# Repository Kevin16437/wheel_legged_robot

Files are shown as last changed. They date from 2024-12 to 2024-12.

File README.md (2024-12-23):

# 轮足机器人  
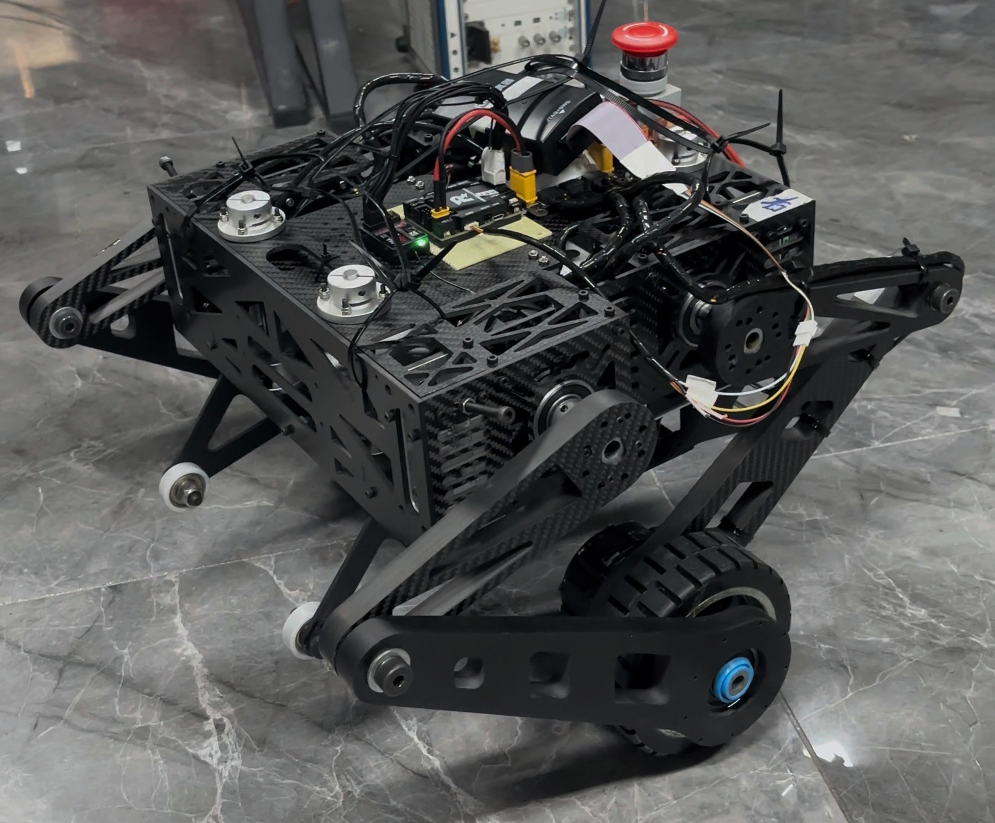
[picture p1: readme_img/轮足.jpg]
轮足

仍在更新完善。代码部分待继续补充说明。  
## 介绍  
本项目的轮足机器人包含6个电机，4个关节电机及2个轮毂电机均使用SG6010单编码器电机，预留出电池仓及主控螺丝孔位于机体底部。主控使用大疆robomaster C型开发板。  
主控代码部分包含另一个开源的仓库：[电机SDK](https://gitee.com/cyberbeast/mwmotorsdk).

## 目录
整个机器人项目被划分为多个部分，分别存放在仓库的不同目录中，每个部分都有更详细的说明，读者可根据需要进行查阅：  
 
- [`hardware`](hardware)：电源分线板PCB文件，由嘉立创专业版导出包含Gerber和AD文件。  
- [`matlab`](matlab)：算法仿真，包含模型建立、算法设计和仿真文件等。  
- [`software`](software)：主控程序，包含STM32代码工程。  
- [`solidworks`](solidworks)：机械结构设计，包含所有零件和总装配体模型文件。 
  
## 关于我们
北京守护兽科技有限公司是一家致力于电机驱动的技术公司，专注于伺服电机驱动板的研究与开发。本开源项目体现了我们对技术分享与社区建设的承诺，欢迎大家提出建议，共同完善和发展轮足机器人技术。
如需技术支持或合作，请联系： luoyongheng@cyberbeast.cn  

## 特别鸣谢  
感谢西格传动对本项目的大力支持。  
[西格传动官网](https://www.siggear.cn/)  

## 开源协议  
本项目采用 GNU 通用公共许可证 v3.0（GPL-3.0） 开源协议发布。你可以自由使用、修改和分发本项目的源代码，但请遵守以下条款：  

- 如果你修改了本项目的代码并发布，必须在发布的代码中包含原作者信息。  
- 发布的衍生作品必须在相同的GPL-3.0协议下发布。  
- 你在使用本项目时，如果与其他代码一起分发，必须将所有源代码公开。  
详细协议内容请参考[LICENSE](LICENSE)。  

***DRIVE THE WORLD WITH CYBERBEAST***

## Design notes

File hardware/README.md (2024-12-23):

# 电源分线板  
本电源分线板由XT60输入电池24V，给六个电机和主控板提供电源。XT30PW包含CAN线接口，每路XT30PW CAN接口可自行并联120Ω电阻（位于PCB背面），外引两路CAN线接口(一路用于调试，一路用于接主控板)。
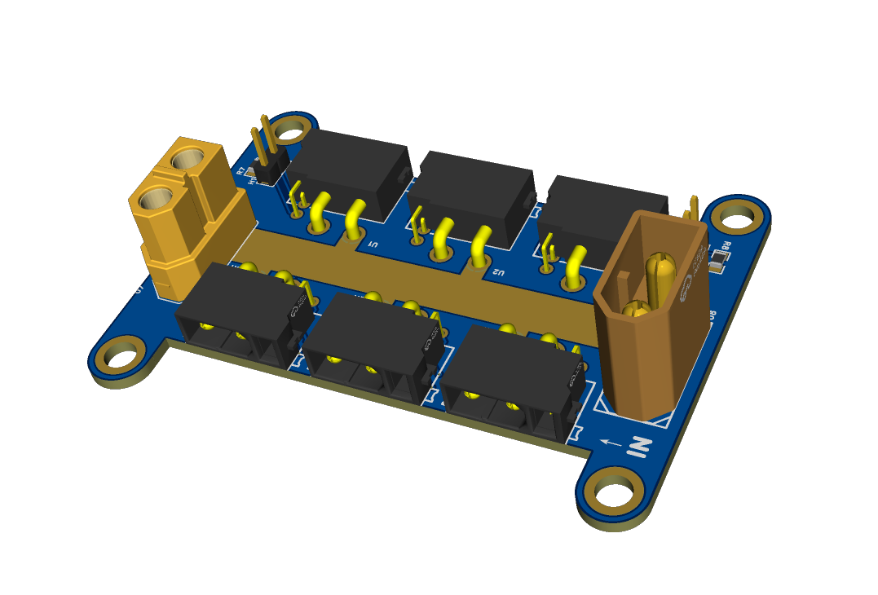
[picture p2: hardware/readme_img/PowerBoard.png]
powerborad
  
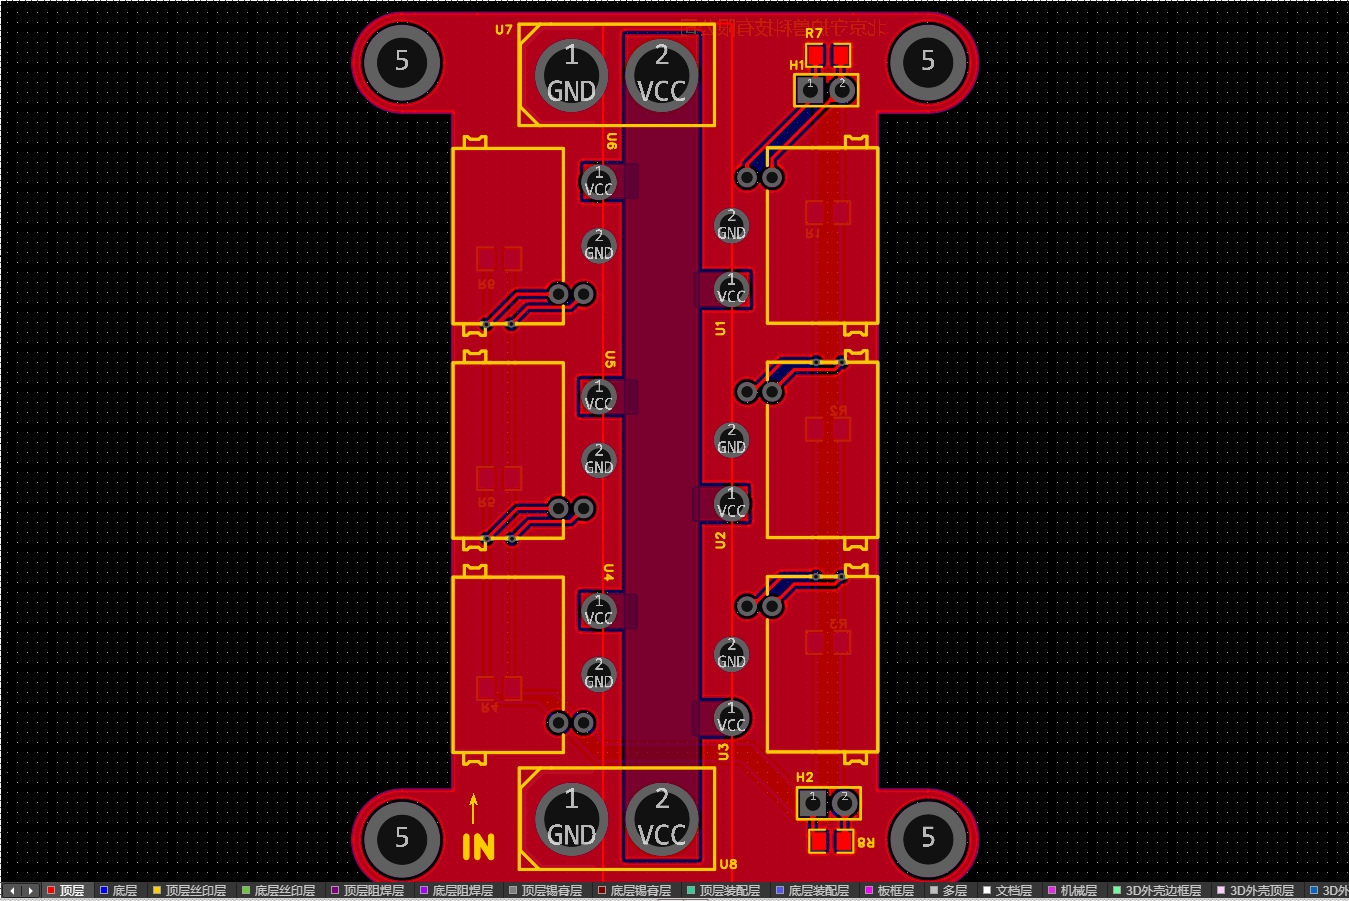
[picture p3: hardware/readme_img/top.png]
top
  
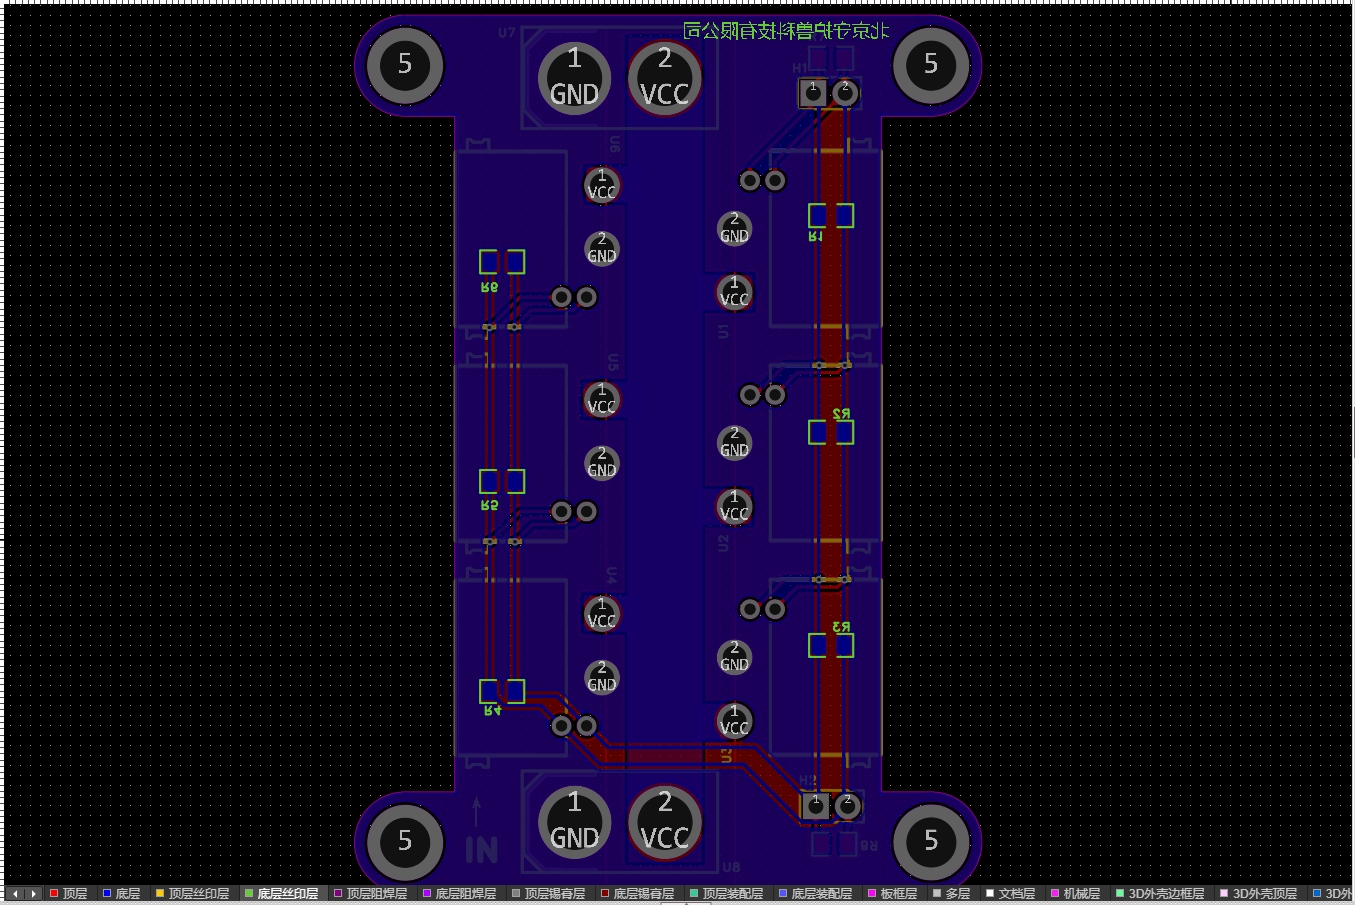
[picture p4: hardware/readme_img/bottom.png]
bottom


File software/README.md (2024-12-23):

# 轮足主控部分  
本代码基于[Esp32WheelLeg](https://github.com/GodsheepYao/Esp32WheelLeg/tree/ChangeTest/esp32-controller/software)进行开发，再次感谢[Skythinker616](https://github.com/Skythinker616)大佬的开源。  
## 说明
本项目主控采用大疆RoboMaster开发板 C 型作为主控板，使用FREERTOS实时系统进行开发；使用板载陀螺仪BMI088;遥控器使用HOT-RC HT-6A遥控器。  
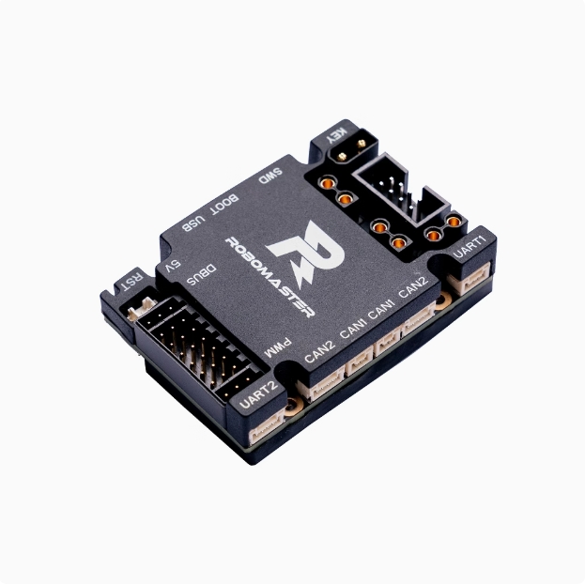
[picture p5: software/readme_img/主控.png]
主控
  
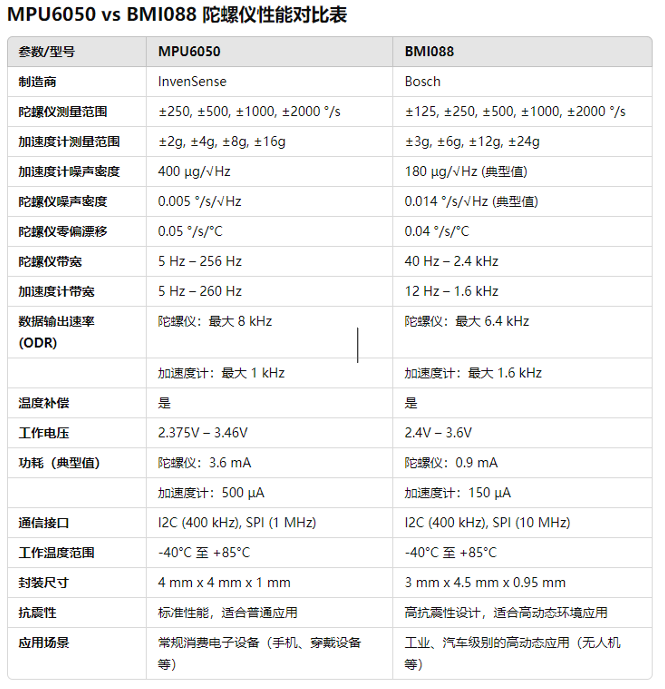
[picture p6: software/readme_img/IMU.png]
IMU
  
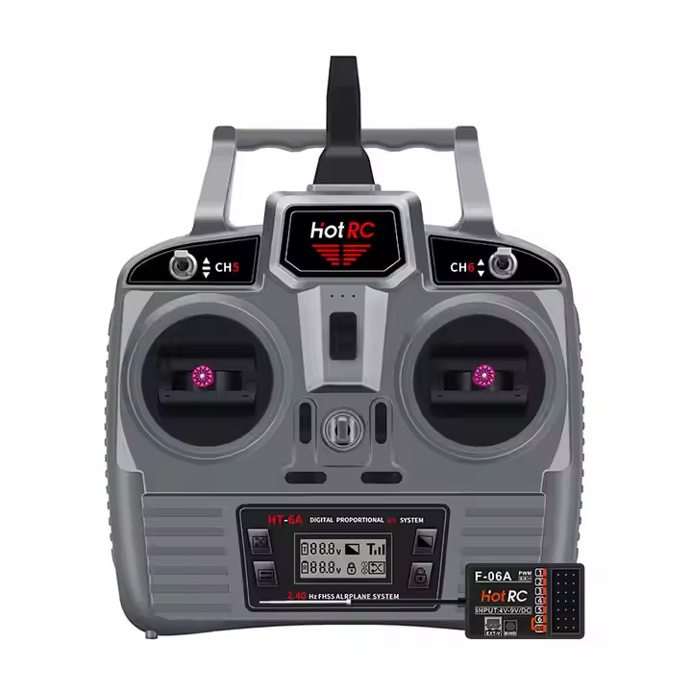
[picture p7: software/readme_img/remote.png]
遥控器
  
## 硬件连接  
六个电机通过分线板连接到一条总线上，通过分线板再连接到主控板上。其中电机CAN ID的编号如下：  
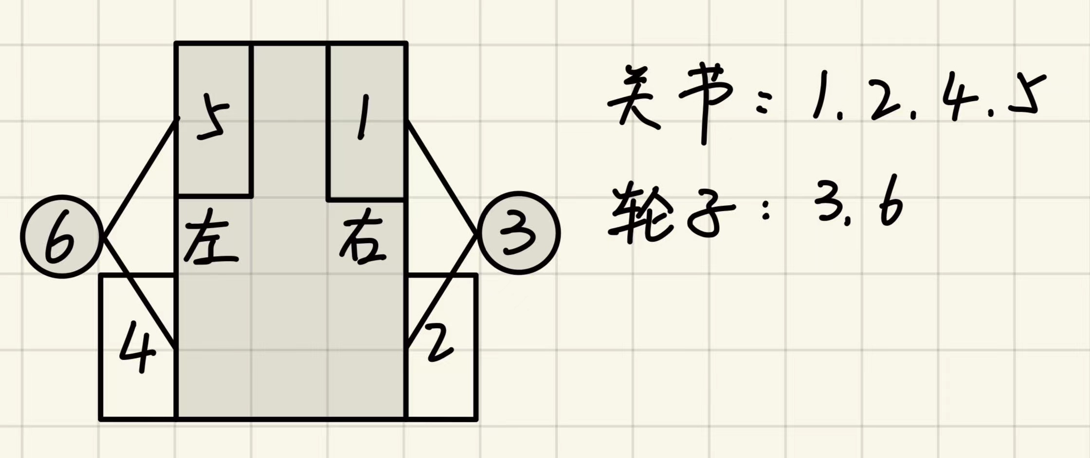
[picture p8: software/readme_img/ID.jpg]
ID
  
## 陀螺仪安装方式  
本程序陀螺仪的安装位置和机械预留安装孔的位置不一样，具体安装位置如下（线有些乱-_-||）：  
安装方式
## 程序框图  
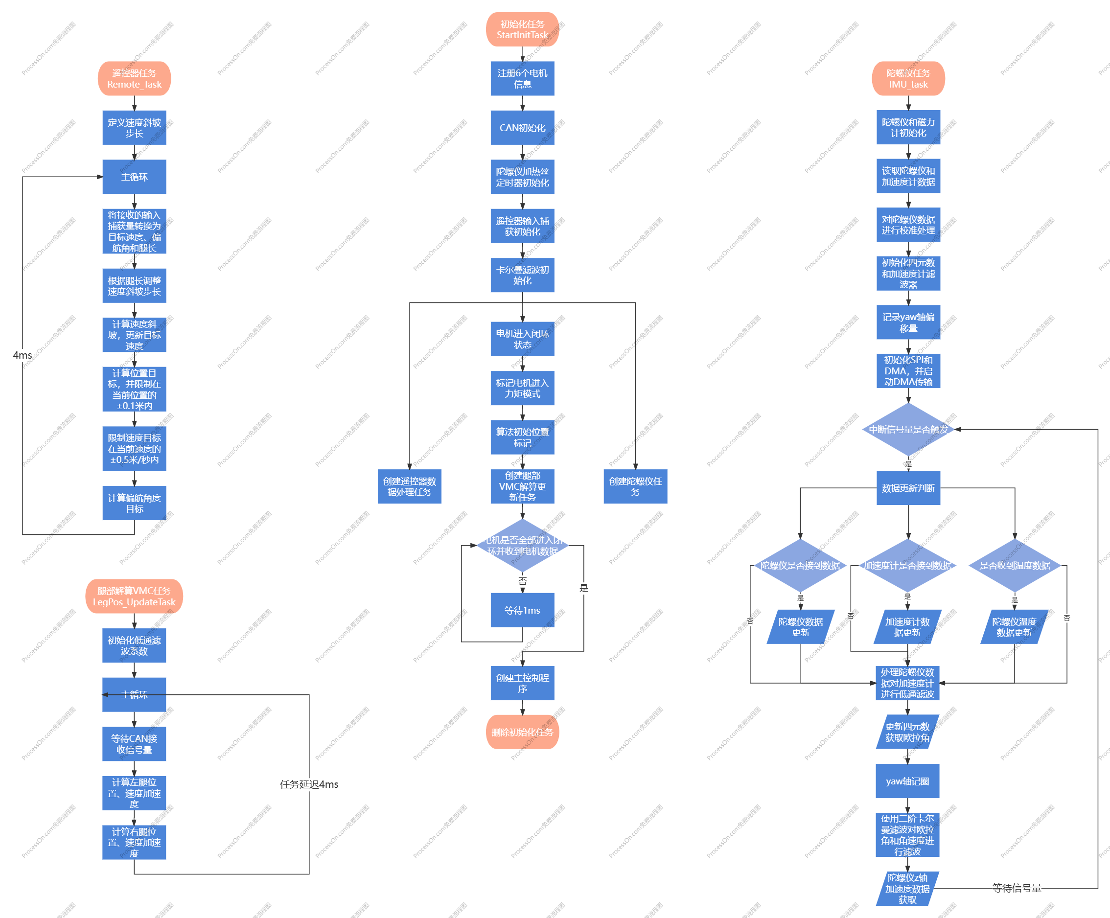
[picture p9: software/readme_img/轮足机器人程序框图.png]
轮足机器人程序框图

主程序框图
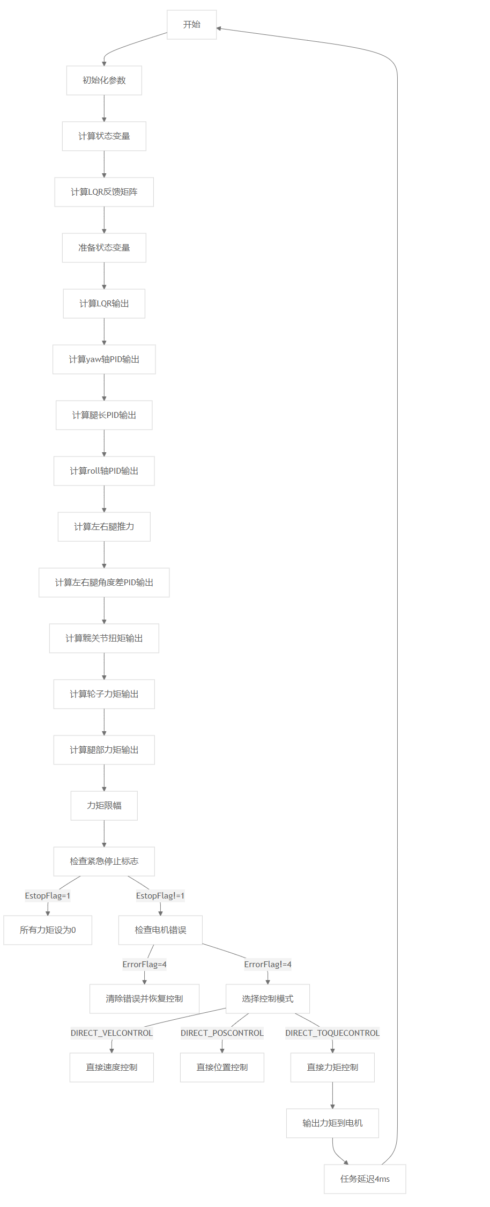
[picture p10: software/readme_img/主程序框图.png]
主程序框图


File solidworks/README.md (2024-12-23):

# SolidWorks 机械模型  
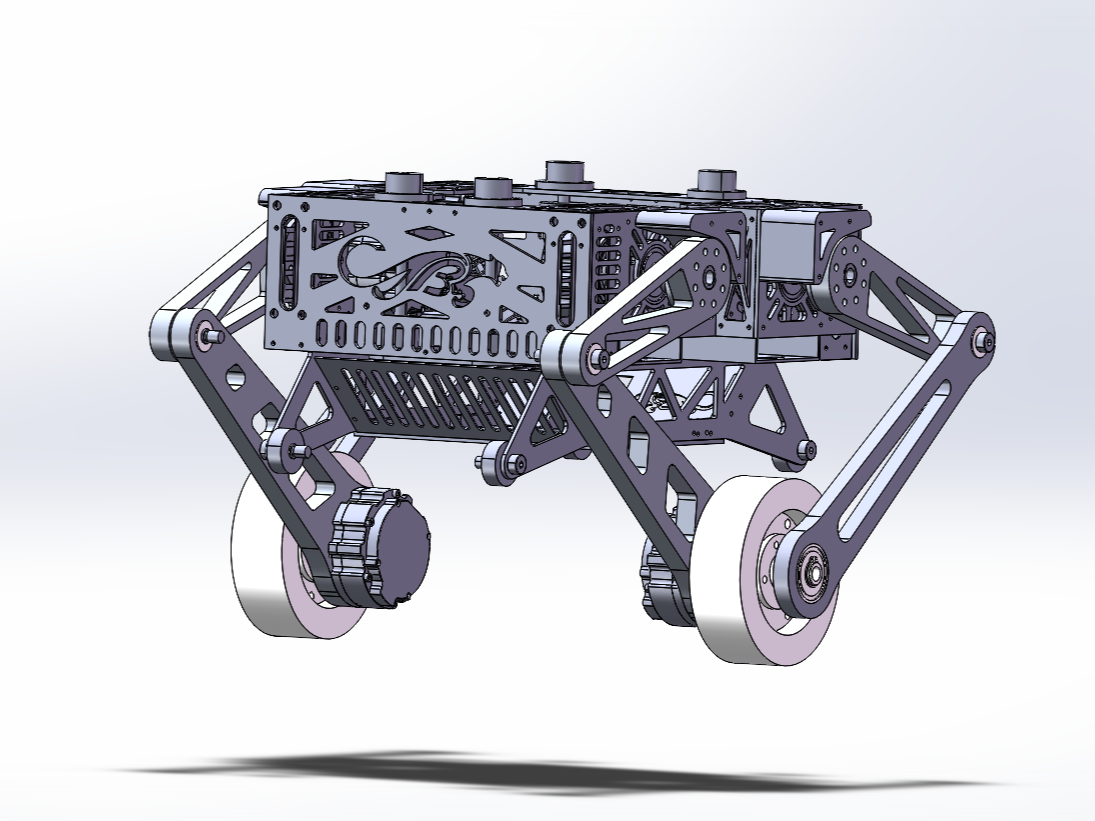
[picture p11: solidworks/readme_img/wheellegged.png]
wheellegged
  
本模型使用SolidWorks 2020 SP5.0设计，可使用玻纤和碳板作为机体主要材料，关节限位使用3D打印制造。  
本目录中装配图文件中的```轮腿总装配体（开源）```文件若出现打开后无法正常显示机体的情况，请按如图操作。  
open  

### 电机选择  
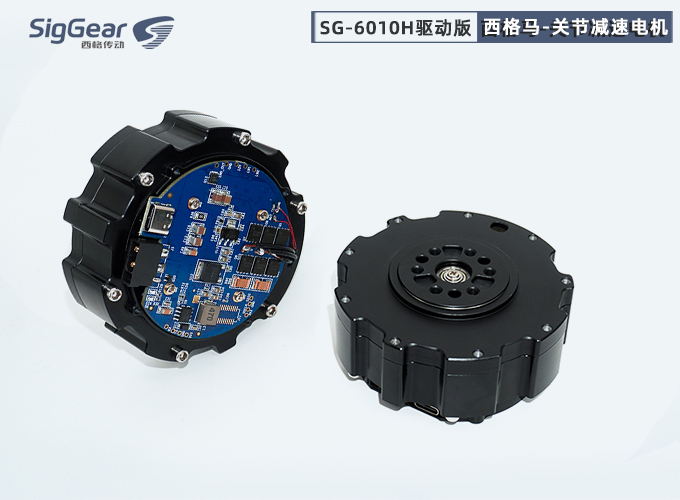
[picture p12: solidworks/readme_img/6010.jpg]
motor
  
关节及轮毂电机均选择SG6010电机，电机参数如下：  
| 电机 | 额定电压 | 堵转扭矩 | 重量 | 购买链接 |
| :--: | :--: | :--: | :--: | :--: |
| SG6010 | 15V-48V DC | 18Nm | 385g | [西格传动](https://www.siggear.cn/product/341.html) |  

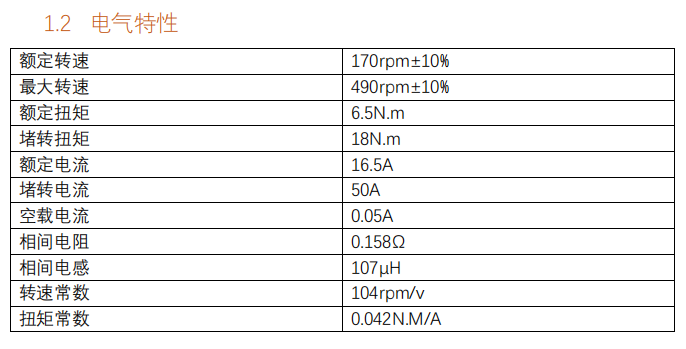
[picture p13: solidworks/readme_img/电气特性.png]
electric
  
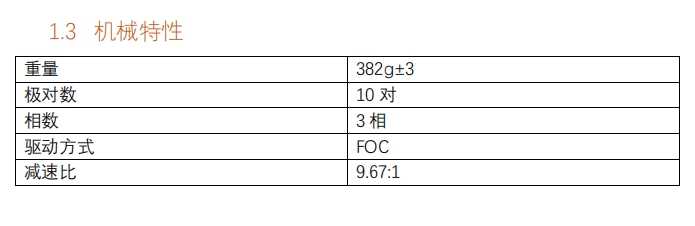
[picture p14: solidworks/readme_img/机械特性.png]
mechnical

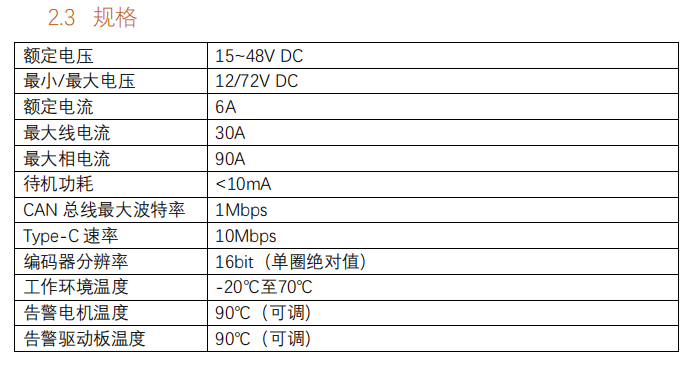
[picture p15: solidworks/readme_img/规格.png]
motor_param

### 电池
电池选用格氏3000mah 24V 75C锂电池，参数如图：  
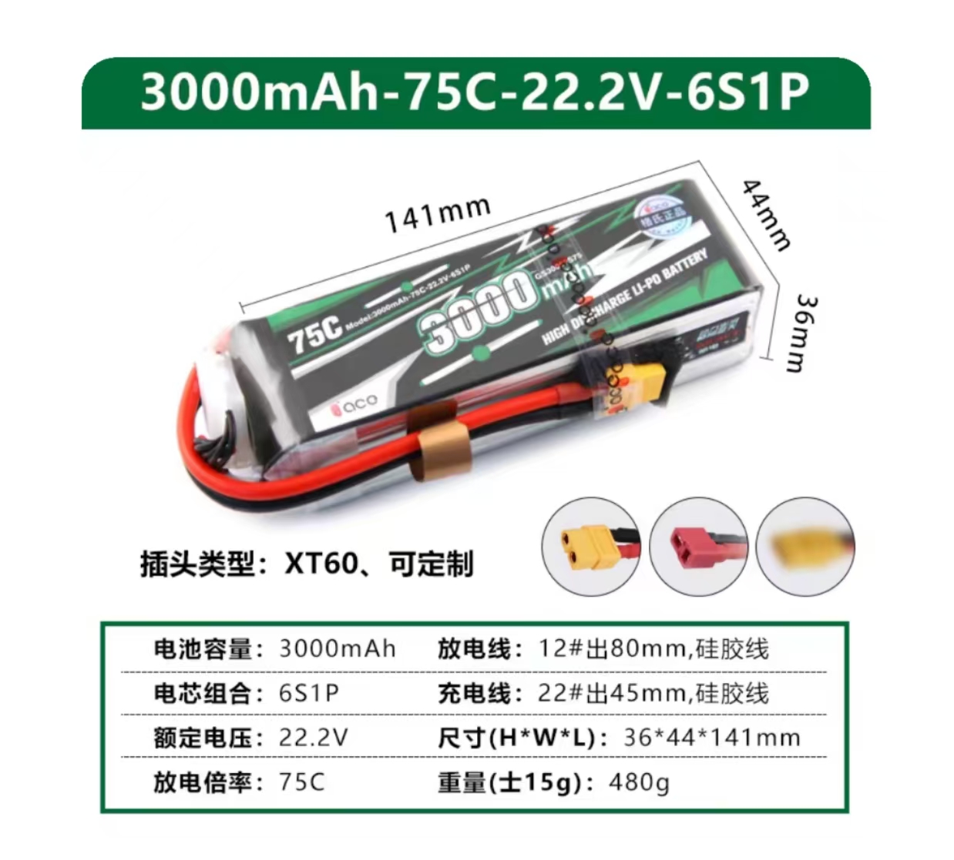
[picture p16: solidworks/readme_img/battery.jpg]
battery


## 其他零件  
其他零件购买链接及价格数量在本目录下的excel文件中。  
零件详单：[轮腿零件详单](轮足零件详单.xlsx)

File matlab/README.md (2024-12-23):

# 模型搭建&算法仿真
***本模型来源：https://github.com/Skythinker616/foc-wheel-legged-robot/tree/master/matlab***   
***作者：[Skythinker616](https://github.com/Skythinker616)***   
十分感谢作者的开源。   
**简体中文 | [English](README_en.md)**   

本项目使用 MATLAB(R2022b) 进行平衡算法的设计和仿真，主要进行了：

- 腿部连杆姿态计算
- 系统状态空间方程建立
- LQR 反馈矩阵计算和拟合
- Simscape Multibody 物理模型搭建
- Simulink 控制算法仿真

---

## 控制算法

平衡算法主要参考了这个[专栏文章](https://zhuanlan.zhihu.com/p/563048952)，仅有少许不同，因此不在此处详述，仅描述大致过程，包含以下几个步骤：

> 注：代码中变量名称与该文章所述基本保持一致，读者可以对照查看

1. 对腿部结构进行化简，求得化简前后各符号的对照关系，从而可以使用电机数据计算出腿部的姿态
2. 求得化简后的虚拟腿受力到电机扭矩的映射关系，从而可以使用VMC思想对化简后的腿部进行控制
3. 进行经典力学分析和符号化简，求得系统状态空间方程
4. 设定LQR中的权重系数，求取反馈矩阵K，并对不同腿长求出的K进行拟合
5. 进行状态反馈控制

---

## 文件介绍

- `leg_func_calc.m`：进行腿部解算和 VMC 映射计算，包含上述步骤1-2，导出以下三个M函数：
	- `leg_pos.m`：可由关节电机角度求得腿部姿态
	- `leg_spd.m`：可由关节电机角度速度求得腿部运动速度
	- `leg_conv.m`：可由虚拟腿目标扭矩和推力求得电机所需输出的力矩
- `sys_calc.m`：求得系统状态方程，求得反馈矩阵，包含上述步骤3-4，导出下述M函数：
	- `lqr_k.m`：代入腿长 L0 后返回该腿长对应的反馈矩阵 K
- `leg_sim.slx`：腿部仿真 Simulink 模型，包含腿部 Multibody 物理模型，用于腿部VMC算法验证
	- `leg_sim_2020a.slx`：导出的旧版本模型，适用 R2020a 及以上版本
- `sys_sim.slx`：整机平衡仿真 Simulink 模型，包含整机 Multibody 物理模型，用于 VMC+LQR 整体算法验证
	- `sys_sim_2020a.slx`：导出的旧版本模型，适用 R2020a 及以上版本

> 注：导出的M函数都在仿真模型中直接使用，使用 MATLAB Coder 工具箱直接转换为C语言后即可直接在实机代码中使用，在本项目主控代码中可以找到同名文件

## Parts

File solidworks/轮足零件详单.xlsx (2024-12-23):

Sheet: 机械
链接 | 名称 | 规格 | 数量 | 备注 | 价格 | 合计
https://item.taobao.com/item.htm?id=37845790021&from=cart&skuId=5143480435166 | 驱动轮 | 125*40mm | 2 |  | 118 | 236
https://item.taobao.com/item.htm?id=679139190572&from=cart&skuId=5045908463514 | 圆法兰 | 内16mm | 4 |  | 14 | 56
https://item.taobao.com/item.htm?id=735269612575&from=cart&skuId=5081573680196 | 轴承 | 外44内30厚11 | 2 |  | 10.64 | 21.28
https://item.taobao.com/item.htm?id=718164083355&from=cart&skuId=5011041237620 | 轴承 | 内16mm外40mm厚12mm | 4 |  | 3.18 | 12.72
https://item.taobao.com/item.htm?id=617375530237&from=cart&skuId=4526512275247 | 法兰轴承 | 内10外19厚7 | 8 |  | 7.28 | 58.24
https://item.taobao.com/item.htm?id=629627302491&from=cart&skuId=4648519155150 | 推力球轴承 | 内10外18厚5.5 | 4 |  | 5.73 | 22.92
https://item.taobao.com/item.htm?id=743331881426&from=cart&skuId=5124933312860 | 圆法兰 | 内16外24高17.5 | 4 |  | 12.9 | 51.6
https://item.taobao.com/item.htm?id=718164083355&from=cart&skuId=5011041237620 | 轴承 | 内16外40高12 | 4 |  | 4.3 | 17.2
https://item.taobao.com/item.htm?id=743492941526&from=cart&skuId=5129994029574 | 光轴固定座 | 内8 | 8 |  | 2.9 | 23.2
https://item.taobao.com/item.htm?id=44033021505&from=cart&skuId=81207330250 | 直线轴承LMF8UU | 内八 | 4 |  | 12 | 48
https://item.taobao.com/item.htm?id=654761225877&from=cart&skuId=4896824522488 | 光轴导轨 | φ8*125 | 4 | 店家可加工，2元一根 | 11.7 | 46.8
https://item.taobao.com/item.htm?id=556365917626&from=cart&skuId=4070935120500 | 避震器安装座上 | 3mm孔径 | 2 |  | 14 | 28
https://item.taobao.com/item.htm?id=556365917626&from=cart&skuId=4216145679357 | 避震器安装座下 | 5mm孔径 | 2 |  | 14 | 28
https://item.taobao.com/item.htm?id=537171387950&from=cart&skuId=3279233048875 | 避震器 | 1-10kg | 1 | 一对 | 39 | 39
https://item.taobao.com/item.htm?id=678396525186&from=cart&skuId=5043982563697 | 六面四方螺母 | M3*16+32-H8*48 | 8 |  | 6.82 | 54.56
https://item.taobao.com/item.htm?id=715027279657&from=cart&skuId=4998431764897 | 四方块螺母 | 8*8*8 m3 | 5 |  | 8 | 40
https://item.taobao.com/item.htm?id=793436606037&from=cart&skuId=5585810966213 | 导向轮 | 内10外30 | 4 |  | 3.79 | 15.16
https://item.taobao.com/item.htm?id=19537038717&from=cart&skuId=5038326263748 | 塞打螺丝 | 内10光杆35 | 4 |  | 1.12 | 4.48
https://item.taobao.com/item.htm?id=19537038717&from=cart&skuId=5038326263744 | 塞打螺丝 | 内10高16 | 4 |  | 1.9 | 7.6
https://item.taobao.com/item.htm?id=694431413784&from=cart&skuId=5523021280578 | 螺丝 | M3*5 | 1 | 50个 | 2.04 | 2.04
 |  | M3*6 | 1 | 100个 | 3.6 | 3.6
 |  | M3*8 | 1 | 100个 | 3.6 | 3.6
 |  | M3*16 | 1 | 50个 | 2.16 | 2.16
 |  | M3*20 | 1 | 50个 | 2.4 | 2.4
 |  | M3*25 | 1 | 50个 | 4.08 | 4.08
 |  | M4*6 | 1 | 50个 | 2.56 | 2.56
 |  | M4*12 | 1 | 50个 | 2.72 | 2.72
 |  | M4*16 | 1 | 50个 | 3.2 | 3.2
 |  | M5*12 | 2 | 100个 | 3.15 | 6.3
 |  | M5*25 | 1 | 50个 | 4.55 | 4.55
 |  | M5*30 | 1 | 20个 | 2.99 | 2.99
 |  | M6*25 | 1 | 50个 | 2.24 | 2.24
https://item.taobao.com/item.htm?id=741730901487&from=cart&skuId=5115074484735 | 轴套 | 10*14*14 | 4 |  | 1.93 | 7.72
https://item.taobao.com/item.htm?id=550329824952&from=cart&skuId=4231382642531 | 防松螺母 | M3 | 4 | 80个 | 1.46 | 5.84
 |  | M4 | 3 | 60个 | 1.65 | 4.95
 |  | M5 | 3 | 60个 | 1.75 | 5.25
 |  | M6 | 5 | 50个 | 1.27 | 6.35
 |  | M10 | 2 | 10个 | 2.72 | 5.44
https://item.taobao.com/item.htm?id=589748020562&from=cart&skuId=4207476530070 | 扳手 | 6——7 | 1 |  | 0.65 | 0.65
 |  | 8——10 | 1 |  | 0.65 | 0.65
 |  | 14——17 | 1 |  | 0.9 | 0.9
https://detail.tmall.com/item.htm?id=680516964370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 | 钢轴 | 直径4长10 | 1 | 100个 | 6 | 6
 | 碳板加工 | 定制 | 1 |  | 2013 | 2013
 |  |  |  |  |  | 2909.95

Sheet: 硬件
链接 | 名称 | 规格 | 数量 | 备注 | 价格 | 合计
https://item.taobao.com/item.htm?id=650012052249&from=cart&skuId=4688213984445 | XT60电源头 | XT60H公/母一套(带护套) | 10 |  | 3.57
https://item.taobao.com/item.htm?id=721245665085&from=cart&skuId=5018779016034 | 红黑硅胶线 | 硅胶红黑线-2芯14AWG/0.3平方5米价 | 5 |  | 6.43
https://item.taobao.com/item.htm?id=548240251040&from=cart&skuId=3892340015403 | 电源充电器 | B6AC+XT60线 | 1 |  | 93
https://item.taobao.com/item.htm?id=554987950181&from=cart&skuId=4978870147813 | 航模电池 | 6s 3000mAh 75C升级版 | 1 |  | 368
https://item.taobao.com/item.htm?id=611226266955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 | robomaster开发板 | C型 | 1 |  | 379
https://item.taobao.com/item.htm?id=528944888311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 | 急停开关 | 红φ22常规 | 1 |  | 5
 |  |  |  |  | 855

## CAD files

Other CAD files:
solidworks/轮腿装配图/KJ90FT33______.STEP.STEP.SLDASM
solidworks/轮腿装配图/NONE_1_1^_X2_897F683C00B79A6C51CF901F753_ASM_SG6010D_asm20240708.stp.STEP.STEP.SLDPRT
solidworks/轮腿装配图/SG6010H_ASM_______2__SG6-206444^_X2_897F683C00B79A6C51CF901F753_ASM_SG6010D_asm20240708.stp.STEP.STEP.SLDPRT
solidworks/轮腿装配图/__________-8.STEP.SLDASM
solidworks/轮腿装配图/SG6010D_asm20240708.stp.STEP-3.STEP.SLDASM
solidworks/轮腿装配图/SG6010D_asm20240708.stp-1.STEP-4.STEP.SLDASM
solidworks/轮腿装配图/SG6010D_asm20240708.stp.STEP-2.STEP.SLDASM
solidworks/轮腿装配图/KJ90FT33______-1.STEP.SLDASM
solidworks/轮腿装配图/MANIFOLD_SOLID_BREP_439299_1^SG6010C-04_5_ASM_1_ASM_SG6010C_ASM_252_ASM_1_ASM_SG6010D_asm20240708.stp.STEP.STEP.SLDPRT
solidworks/轮腿装配图/SG6010C-04_5_ASM_1_ASM^SG6010C_ASM_252_ASM_1_ASM_SG6010D_asm20240708.stp.STEP.STEP.SLDASM
solidworks/轮腿装配图/SG6010D_asm20240708.stp-1.STEP-5.STEP.SLDASM
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

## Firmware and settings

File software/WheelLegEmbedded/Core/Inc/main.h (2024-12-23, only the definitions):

#define RSTN_IST8310_Pin GPIO_PIN_6
#define RSTN_IST8310_GPIO_Port GPIOG
#define DRDY_IST8310_Pin GPIO_PIN_3
#define DRDY_IST8310_GPIO_Port GPIOG
#define DRDY_IST8310_EXTI_IRQn EXTI3_IRQn
#define CS1_ACCEL_Pin GPIO_PIN_4
#define CS1_ACCEL_GPIO_Port GPIOA
#define INT1_ACCEL_Pin GPIO_PIN_4
#define INT1_ACCEL_GPIO_Port GPIOC
#define INT1_ACCEL_EXTI_IRQn EXTI4_IRQn
#define INT1_GYRO_Pin GPIO_PIN_5
#define INT1_GYRO_GPIO_Port GPIOC
#define INT1_GYRO_EXTI_IRQn EXTI9_5_IRQn
#define CS1_GYRO_Pin GPIO_PIN_0
#define CS1_GYRO_GPIO_Port GPIOB

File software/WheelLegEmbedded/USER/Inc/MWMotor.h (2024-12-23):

/**
 * @file       MWMotor.h
 * @brief      MW电机软件开发工具包(SDK)的头文件
 * @details    此头文件包含了与MW电机交互所需的所有函数声明、宏定义、数据类型和结构体定义。
 *
 * @author     罗永恒, 姚宇鸽
 * @date       2024.7.17
 * @version    1.0
 * @copyright  Copyright (c) 2024 北京守护兽科技有限公司
 */

#ifndef __ODRIVEMOTOR_H
#define __ODRIVEMOTOR_H

#include <stdint.h>
#include <string.h>

#ifdef __cplusplus
extern "C" {
#endif

/* 定义最大总线数量 */
#define MAX_BUS_NUM 8
/* 定义每个总线上最多电机的数量 */
#define MAX_MOTOR_NUM_PER_BUS 16

typedef enum {
    MW_ERROR_SUCCESS = 0,                
    MW_ERROR_OUT_OF_RANGE = 1,           
} MW_ERROR;

typedef enum {
    MW_ENDPOINT_DATA_TYPE_INT = 0,       
    MW_ENDPOINT_DATA_TYPE_FLOAT = 1,     
} MW_ENDPOINT_DATA_TYPE;

typedef struct {
    MW_ENDPOINT_DATA_TYPE type;          
    union {
        int32_t intData;                 
        float floatData;                 
    } data;                                
} MW_ENDPOINT_DATA;

typedef enum {
    MW_ENDPOINT_OPCODE_READ = 0,
    MW_ENDPOINT_OPCODE_WRITE = 1,
} MW_ENDPOINT_OPCODE;

typedef struct {
    MW_ENDPOINT_OPCODE opcode;
    uint16_t id;
    MW_ENDPOINT_DATA data;
} MW_ENDPOINT;

/**
 * @brief MW_CMD_ID指令枚举
 */
typedef enum {           
    MW_HEARTBEAT_CMD                  = 0x001,                   //!<@brief 电机心跳周期数据
    MW_ESTOP_CMD                      = 0x002,                   //!<@brief 紧急停止
    MW_GET_ERROR_CMD                  = 0x003,                   //!<@brief 获取错误
    MW_RXSDO_CMD                      = 0x004,                   //!<@brief 接收SDO
    MW_TXSDO_CMD                      = 0x005,                   //!<@brief 发送SDO
    MW_SET_AXIS_NODE_ID_CMD           = 0x006,                   //!<@brief 设置电机节点ID
    MW_SET_AXIS_STATE_CMD             = 0x007,                   //!<@brief 设置电机状态
    MW_MIT_CONTROL_CMD                = 0x008,                   //!<@brief MIT控制
    MW_GET_ENCODER_ESTIMATES_CMD      = 0x009,                   //!<@brief 获取编码器估计值
    MW_GET_ENCODER_COUNT_CMD          = 0x00A,                   //!<@brief 获取编码器计数
    MW_SET_CONTROLLER_MODE_CMD        = 0x00B,                   //!<@brief 设置控制模式
    MW_SET_INPUT_POS_CMD              = 0x00C,                   //!<@brief 设置输入位置
    MW_SET_INPUT_VEL_CMD              = 0x00D,                   //!<@brief 设置输入速度
    MW_SET_INPUT_TORQUE_CMD           = 0x00E,                   //!<@brief 设置输入力矩
    MW_SET_LIMITS_CMD                 = 0x00F,                   //!<@brief 设置速度电流限制
    MW_START_ANTICOGGING_CMD          = 0x010,                   //!<@brief 进行力矩纹波校准
    MW_SET_TRAJ_VEL_LIMIT_CMD         = 0x011,                   //!<@brief 滑行速度最大值
    MW_SET_TRAJ_ACCEL_LIMIT_CMD       = 0x012,                   //!<@brief 滑行加（减）速度最大值
    MW_SET_TRAJ_INERTIA_CMD           = 0x013,                   //!<@brief 惯性系数
    MW_GET_IQ_CMD                     = 0x014,                   //!<@brief 获取电机相电流配置    
    MW_GET_SENSORLESS_ESTIMATES_CMD   = 0x015,                   //!<@brief 获取无感估计值
    MW_REBOOT_CMD                     = 0x016,                   //!<@brief 重启
    MW_GET_BUS_VOLTAGE_CURRENT_CMD    = 0x017,                   //!<@brief 获取总线电压电流
    MW_CLEAR_ERRORS_CMD               = 0x018,                   //!<@brief 清除错误
    MW_SET_LINEAR_COUNT_CMD           = 0x019,                   //!<@brief 设置编码器计数
    MW_SET_POS_GAIN_CMD               = 0x01A,                   //!<@brief 设置位置增益
    MW_SET_VEL_GAIN_CMD               = 0x01B,                   //!<@brief 设置速度增益
    MW_GET_TORQUES_CMD                = 0x01C,                   //!<@brief 获取力矩
    MW_GET_POWERS_CMD                 = 0x01D,                   //!<@brief 获取功率
    MW_DISABLE_CAN_CMD                = 0x01E,                   //!<@brief 禁用CAN
    MW_SAVE_CONFIGURATION_CMD         = 0x01F                    //!<@brief 保存配置
} MW_CMD_ID;

/**
 * @brief 电机状态枚举
 */
typedef enum { 
    MW_AXIS_STATE_UNDEFINED                            = 0x0,    //!<@brief 未定义状态，表示初始化或未配置状态
    MW_AXIS_STATE_IDLE                                 = 0x1,    //!<@brief 空闲状态，电机不工作，PWM被禁用
    MW_AXIS_STATE_STARTUP_SEQUENCE                     = 0x2,    //!<@brief 启动序列状态，电机启动时的预设操作
    MW_AXIS_STATE_FULL_CALIBRATION_SEQUENCE            = 0x3,    //!<@brief 完全校准序列状态，包括电机和编码器的全面校准
    MW_AXIS_STATE_MOTOR_CALIBRATION                    = 0x4,    //!<@brief 电机校准状态，用于测量电机的相电阻和相电感
    MW_AXIS_STATE_ENCODER_INDEX_SEARCH                 = 0x6,    //!<@brief 编码器索引搜索状态，寻找编码器的零点位置
    MW_AXIS_STATE_ENCODER_OFFSET_CALIBRATION           = 0x7,    //!<@brief 编码器偏移校准状态，校准编码器的相对位置
    MW_AXIS_STATE_CLOSED_LOOP_CONTROL                  = 0x8,    //!<@brief 闭环控制状态，电机根据反馈进行精确控制
    MW_AXIS_STATE_LOCKIN_SPIN                          = 0x9,    //!<@brief 锁定自转状态，用于校准过的电机保持稳定旋转（只有校准过电机才能进入）
    MW_AXIS_STATE_ENCODER_DIR_FIND                     = 0xA,    //!<@brief 编码器方向搜索状态，确定编码器的旋转方向（只有校准过电机才能进入）
    MW_AXIS_STATE_HOMING                               = 0xB,    //!<@brief 零点搜索状态，寻找电机的机械零点
    MW_AXIS_STATE_ENCODER_HALL_POLARITY_CALIBRATION    = 0xC,    //!<@brief 编码器霍尔传感器极性校准状态
    MW_AXIS_STATE_ENCODER_HALL_PHASE_CALIBRATION       = 0XD,    //!<@brief 编码器霍尔传感器相位校准状态
    MW_AXIS_STATE_ANTICOGGING_CALIBRATION              = 0XE     //!<@brief 进行力矩纹波校准
} MW_MOTER_STATE;

/**
 * @brief 电机控制模式枚举
 */
typedef enum { 
    MW_VOLTAGE_CONTROL          = 0,        //!<@brief 电压控制
    MW_TORQUE_CONTROL           = 1,        //!<@brief 力矩控制
    MW_VELOCITY_CONTROL         = 2,        //!<@brief 速度控制
    MW_POSITION_CONTROL         = 3         //!<@brief 位置控制
} MW_CONTROL_MODE;

/**
 * @brief 电机输入模式枚举
 */
typedef enum { 
    MW_IDLE_INPUT               = 0,        //!<@brief 闲置
    MW_DIRECT_CONTROL_INPUT     = 1,        //!<@brief 直接控制        
    MW_RAMP_RATE_INPUT          = 2,        //!<@brief 速度斜坡
    MW_POSITION_FILTERING_INPUT = 3,        //!<@brief 位置滤波
    MW_TRAPEZOIDAL_CURVE_INPUT  = 5,        //!<@brief 梯形曲线
    MW_TORQUE_RAMP_INPUT        = 6,        //!<@brief 力矩斜坡
    MW_MIT_INPUT                = 9         //!<@brief MIT模式控制
} MW_INPUT_MODE;

/**
 * @brief 电机错误类型枚举
 */
typedef enum {
    MW_MOTOR_ERROR = 0,                     //!<@brief 电机异常
    MW_ENCODER_ERROR = 1,                   //!<@brief 编码器异常
    MW_SENSORLESS_ERROR = 2,                //!<@brief 无感异常
    MW_CONTROLLER_ERROR = 3,                //!<@brief 控制器异常
} MW_ERROR_TYPE;

/**
 * @brief MW电机MIT模式数据结构体
 */
typedef struct {
    double targetPos;                       //!<@brief 目标位置
    double ffVel;                           //!<@brief 速度前馈
    double kp;                              //!<@brief 比例系数
    double kd;                              //!<@brief 微分系数
    double ffTorque;                        //!<@brief 前馈力矩
} MW_MIT_CTRL_INPUT;
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

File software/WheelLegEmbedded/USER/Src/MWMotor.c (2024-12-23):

#include "MWMotor.h"

/* 所有总线挂的所有电机访问信息 */
MW_MOTOR_ACCESS_INFO motors[MAX_BUS_NUM][MAX_MOTOR_NUM_PER_BUS];

uint8_t MWRegisterMotor(MW_MOTOR_ACCESS_INFO motor) {
    if(motor.busId >= MAX_BUS_NUM || motor.nodeId >= MAX_MOTOR_NUM_PER_BUS) 
        return MW_ERROR_OUT_OF_RANGE;
    motors[motor.busId][motor.nodeId] = motor;
    return MW_ERROR_SUCCESS;
}

void MWEstop(uint8_t busId, uint8_t nodeId) {
    if (busId >= MAX_BUS_NUM || nodeId >= MAX_MOTOR_NUM_PER_BUS) 
        return;
    MotorSender sender = motors[busId][nodeId].sender;
    if (sender == 0) return;

    uint8_t txBuff[8] = { 0 };
    sender(busId, ((uint16_t)nodeId << 5) | MW_ESTOP_CMD, txBuff, sizeof(txBuff));
}

void MWGetMotorError(uint8_t busId, uint8_t nodeId, MW_ERROR_TYPE errorType) {
    if (busId >= MAX_BUS_NUM || nodeId >= MAX_MOTOR_NUM_PER_BUS) 
        return;
    MotorSender sender = motors[busId][nodeId].sender;
    if (sender == 0) return;

    uint8_t txBuff[8] = { 0 };
    txBuff[0] = errorType;
    sender(busId, ((uint16_t)nodeId << 5) | MW_GET_ERROR_CMD, txBuff, sizeof(txBuff));
}

void MWRxTxSdo(uint8_t busId, uint8_t nodeId, MW_ENDPOINT endpointData) {
    if (busId >= MAX_BUS_NUM || nodeId >= MAX_MOTOR_NUM_PER_BUS) 
        return;
    MotorSender sender = motors[busId][nodeId].sender;
    if (sender == 0) return;

    uint8_t txBuff[8] = { 0 };
    txBuff[0] = endpointData.opcode;
    *(uint16_t *)&txBuff[1] = endpointData.id;
    memcpy(&txBuff[4], &endpointData.data.data, 4);
    motors[busId][nodeId].motorData->EndpointData.data.type = endpointData.data.type;
    sender(busId, ((uint16_t)nodeId << 5) | ((endpointData.opcode == MW_ENDPOINT_OPCODE_READ) ? MW_RXSDO_CMD : MW_TXSDO_CMD), txBuff, 8);
}

void MWSetAxisNodeID(uint8_t busId, uint8_t nodeId, uint8_t newNodeId, MW_MOTOR_ACCESS_INFO *motorInfo) {
    if (busId >= MAX_BUS_NUM || nodeId >= MAX_MOTOR_NUM_PER_BUS) 
        return;
    MotorSender sender = motors[busId][nodeId].sender;
    if (sender == 0) return;

    uint8_t txBuff[8] = { 0 };
    txBuff[0] = newNodeId;
    sender(busId, ((uint16_t)nodeId << 5) | MW_SET_AXIS_NODE_ID_CMD, txBuff, sizeof(txBuff));
    memcpy(&motors[busId][newNodeId], motorInfo, sizeof(motors[busId][newNodeId]));
    motors[busId][newNodeId].motorData->nodeId = newNodeId;
}

void MWSetAxisState(uint8_t busId, uint8_t nodeId, MW_MOTER_STATE state) {
    if (busId >= MAX_BUS_NUM || nodeId >= MAX_MOTOR_NUM_PER_BUS) 
        return;
    MotorSender sender = motors[busId][nodeId].sender;
    if (sender == 0) return;

    uint8_t txBuff[8] = { 0 };
    memcpy(txBuff, &state, 4);
    sender(busId, ((uint16_t)nodeId << 5) | MW_SET_AXIS_STATE_CMD, txBuff, sizeof(txBuff));
}

void MWMitControl(uint8_t busId, uint8_t nodeId, MW_MIT_CTRL_INPUT *mit) {
    if (busId >= MAX_BUS_NUM || nodeId >= MAX_MOTOR_NUM_PER_BUS) 
        return;
    MotorSender sender = motors[busId][nodeId].sender;
    if (sender == 0) return;

    uint8_t txBuff[8] = { 0 };
    int16_t pos_int = (int16_t)((mit->targetPos + 12.5f) * 65535.0f / 25.0f);
    int16_t vel_int = (int16_t)((mit->ffVel + 65.0f) * 4095.0f / 130.0f);
    int16_t kp_int = (int16_t)(mit->kp * 4095.0f / 500.0f);
    int16_t kd_int = (int16_t)(mit->kd * 4095.0f / 5.0f);
    int16_t t_int = (int16_t)((mit->ffTorque + 50.0f) * 4095.0f / 100.0f);
    txBuff[0] = pos_int >> 8;
    txBuff[1] = pos_int & 0xFF;
    txBuff[2] = vel_int >> 4;
    txBuff[3] = ((vel_int & 0xF) << 4) + (kp_int >> 8);
    txBuff[4] = kp_int & 0xFF;
    txBuff[5] = kd_int >> 4;
    txBuff[6] = ((kd_int & 0xF) << 4) + (t_int >> 8);
    txBuff[7] = t_int & 0xFF;
    sender(busId, ((uint16_t)nodeId << 5) | MW_MIT_CONTROL_CMD, txBuff, sizeof(txBuff));
}

void MWGetEncoderEstimates(uint8_t busId, uint8_t nodeId) {
    if (busId >= MAX_BUS_NUM || nodeId >= MAX_MOTOR_NUM_PER_BUS)
        return;
    MotorSender sender = motors[busId][nodeId].sender;
    if (sender == 0) return;

    uint8_t txBuff[8] = { 0 };
    sender(busId, ((uint16_t)nodeId << 5) | MW_GET_ENCODER_ESTIMATES_CMD, txBuff, sizeof(txBuff));
}

void MWGetEncoderCount(uint8_t busId, uint8_t nodeId) {
    if (busId >= MAX_BUS_NUM || nodeId >= MAX_MOTOR_NUM_PER_BUS)
        return;
    MotorSender sender = motors[busId][nodeId].sender;
    if (sender == 0) return;

    uint8_t txBuff[8] = { 0 };
    sender(busId, ((uint16_t)nodeId << 5) | MW_GET_ENCODER_COUNT_CMD, (uint8_t*)txBuff, sizeof(txBuff));
}

void MWSetControllerMode(uint8_t busId, uint8_t nodeId, MW_CONTROL_MODE ctrlMode, MW_INPUT_MODE inputMode) {
    if (busId >= MAX_BUS_NUM || nodeId >= MAX_MOTOR_NUM_PER_BUS) 
        return;
    MotorSender sender = motors[busId][nodeId].sender;
    if (sender == 0) return;

    uint8_t txBuff[8] = { 0 };
    memcpy(&txBuff[0], (uint8_t*)&ctrlMode, 4);
    memcpy(&txBuff[4], (uint8_t*)&inputMode, 4);
    sender(busId, ((uint16_t)nodeId << 5) | MW_SET_CONTROLLER_MODE_CMD, (uint8_t*)txBuff, sizeof(txBuff));
}

void MWPosControl(uint8_t busId, uint8_t nodeId, float inputPos, int16_t velFF, int16_t torqueFF) {
    if (busId >= MAX_BUS_NUM || nodeId >= MAX_MOTOR_NUM_PER_BUS) 
        return;
    MotorSender sender = motors[busId][nodeId].sender;
    if (sender == 0) return;

    uint8_t txBuff[8] = { 0 };
    memcpy(&txBuff[0], (uint8_t*)&inputPos, 4);
    memcpy(&txBuff[4], (uint8_t*)&velFF, 2);
    memcpy(&txBuff[6], (uint8_t*)&torqueFF, 2);
    sender(busId, ((uint16_t)nodeId << 5) | MW_SET_INPUT_POS_CMD, (uint8_t*)txBuff, sizeof(txBuff));
}

void MWVelControl(uint8_t busId, uint8_t nodeId, float inputVel, float torqueFF) {
    if (busId >= MAX_BUS_NUM || nodeId >= MAX_MOTOR_NUM_PER_BUS) 
        return;
    MotorSender sender = motors[busId][nodeId].sender;
    if (sender == 0) return;

    uint8_t txBuff[8] = { 0 };
    memcpy(&txBuff[0], (uint8_t*)&inputVel, 4);
    memcpy(&txBuff[4], (uint8_t*)&torqueFF, 4);
    sender(busId, ((uint16_t)nodeId << 5) | MW_SET_INPUT_VEL_CMD, (uint8_t*)txBuff, sizeof(txBuff)); 
}

void MWTorqueControl(uint8_t busId, uint8_t nodeId, float inputTorque) {
    if (busId >= MAX_BUS_NUM || nodeId >= MAX_MOTOR_NUM_PER_BUS) 
        return;
    MotorSender sender = motors[busId][nodeId].sender;
    if (sender == 0) return;

    uint8_t txBuff[8] = { 0 };
    memcpy(&txBuff[0], (uint8_t*)&inputTorque, 4);
    sender(busId, ((uint16_t)nodeId << 5) | MW_SET_INPUT_TORQUE_CMD, (uint8_t*)txBuff, sizeof(txBuff)); 
}

void MWSetLimits(uint8_t busId, uint8_t nodeId, float velLim, float currLim) {
    if (busId >= MAX_BUS_NUM || nodeId >= MAX_MOTOR_NUM_PER_BUS) 
        return;
    MotorSender sender = motors[busId][nodeId].sender;
    if (sender == 0) return;

    uint8_t txBuff[8] = { 0 };
    memcpy(&txBuff[0], (uint8_t*)&velLim, 4);
    memcpy(&txBuff[4], (uint8_t*)&currLim, 4);
    sender(busId, ((uint16_t)nodeId << 5) | MW_SET_LIMITS_CMD, (uint8_t*)txBuff, sizeof(txBuff));  
}
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

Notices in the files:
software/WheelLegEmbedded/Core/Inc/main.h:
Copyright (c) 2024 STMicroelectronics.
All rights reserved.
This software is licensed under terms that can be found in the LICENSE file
